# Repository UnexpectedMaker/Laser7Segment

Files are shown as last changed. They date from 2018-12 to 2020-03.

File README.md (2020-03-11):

# Laser7Segment Display Library
An API that lets you display numbers and letters on Laser7Segment RGB LED displays that are available from [tindie](https://www.tindie.com/products/seonr/laser-segment-display/)

You can find the Open Source hardware PCB design and Gerber files here too as well as the DXF laser cut design files

## Installing and Use
The downloaded code should be added to your arduino IDE libraries folder, and the library requires the [Adafruit NeoPixel library](https://github.com/adafruit/Adafruit_NeoPixel) for it to function.

To include the Laser7Segment library in your project:

    #include <Laser7Segment.h>

You can then initialise the display with the following line that includes the number of Laser7Segment digits and the GPIO to control them:

    Laser7Segment disp( 5, 4 );

You then start the display with the bebin method, passing the brightness:

    disp.Begin(80);

The you simply pass the display the String you would like displayed and a color:

    disp.DisplayText( "1234", disp.Color( 255,0,0) );

Enjoy!

# Support Unexpected Maker

I love designing, making and releasing our projects as open source. I do it because I believe it’s important to share knowledge and give back to the community, like many have done before me. It helps us all learn and grow.

That said, a lot of time, effort and finances have gone into designing and releasing these files, so please consider supporting me by buy some of my TiinyPICO products:

https://tinypico.com/shop

Or by buying one of our products on tindie:

https://www.tindie.com/stores/seonr/

Or by becoming a Patron:

https://www.patreon.com/unexpectedmaker

# Unexpected Maker
http://youtube.com/c/unexpectedmaker

http://twitter.com/unexpectedmaker

https://www.facebook.com/unexpectedmaker/

https://www.instagram.com/unexpectedmaker/

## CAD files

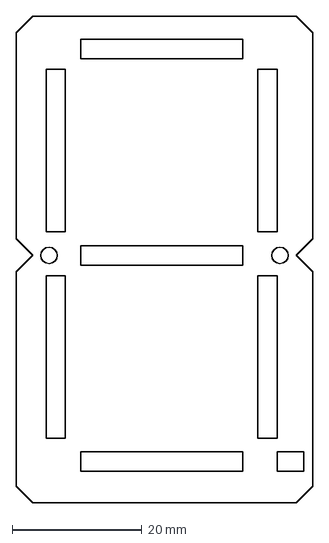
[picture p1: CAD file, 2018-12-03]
Design/LaserSegment_7_Segment_Back.dxf
45.7 x 74.9 mm

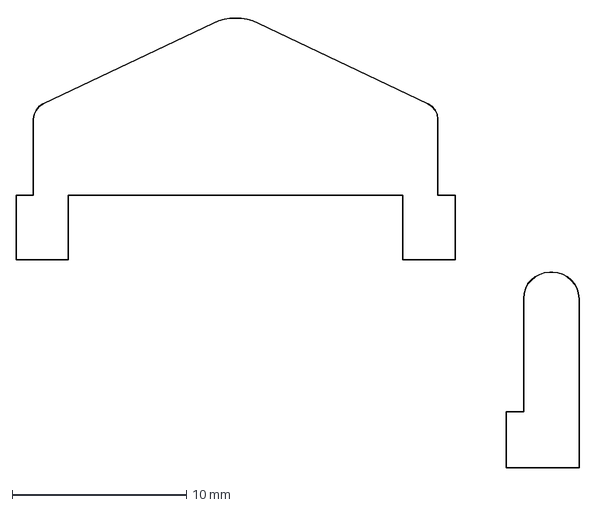
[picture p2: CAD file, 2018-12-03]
Design/LaserSegment_7_Segments.dxf
32.3 x 25.9 mm

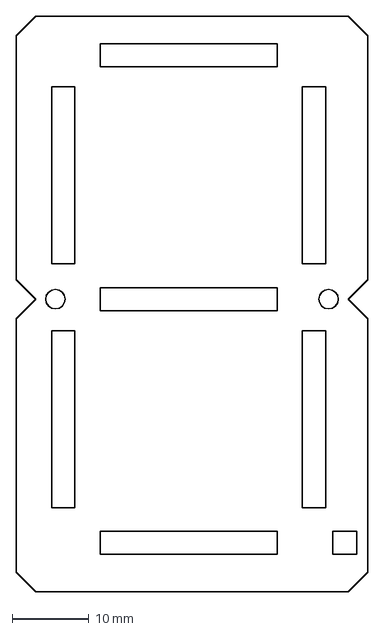
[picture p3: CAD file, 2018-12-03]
Design/LaserSegment_7_Segment_Front.dxf
45.7 x 74.9 mm

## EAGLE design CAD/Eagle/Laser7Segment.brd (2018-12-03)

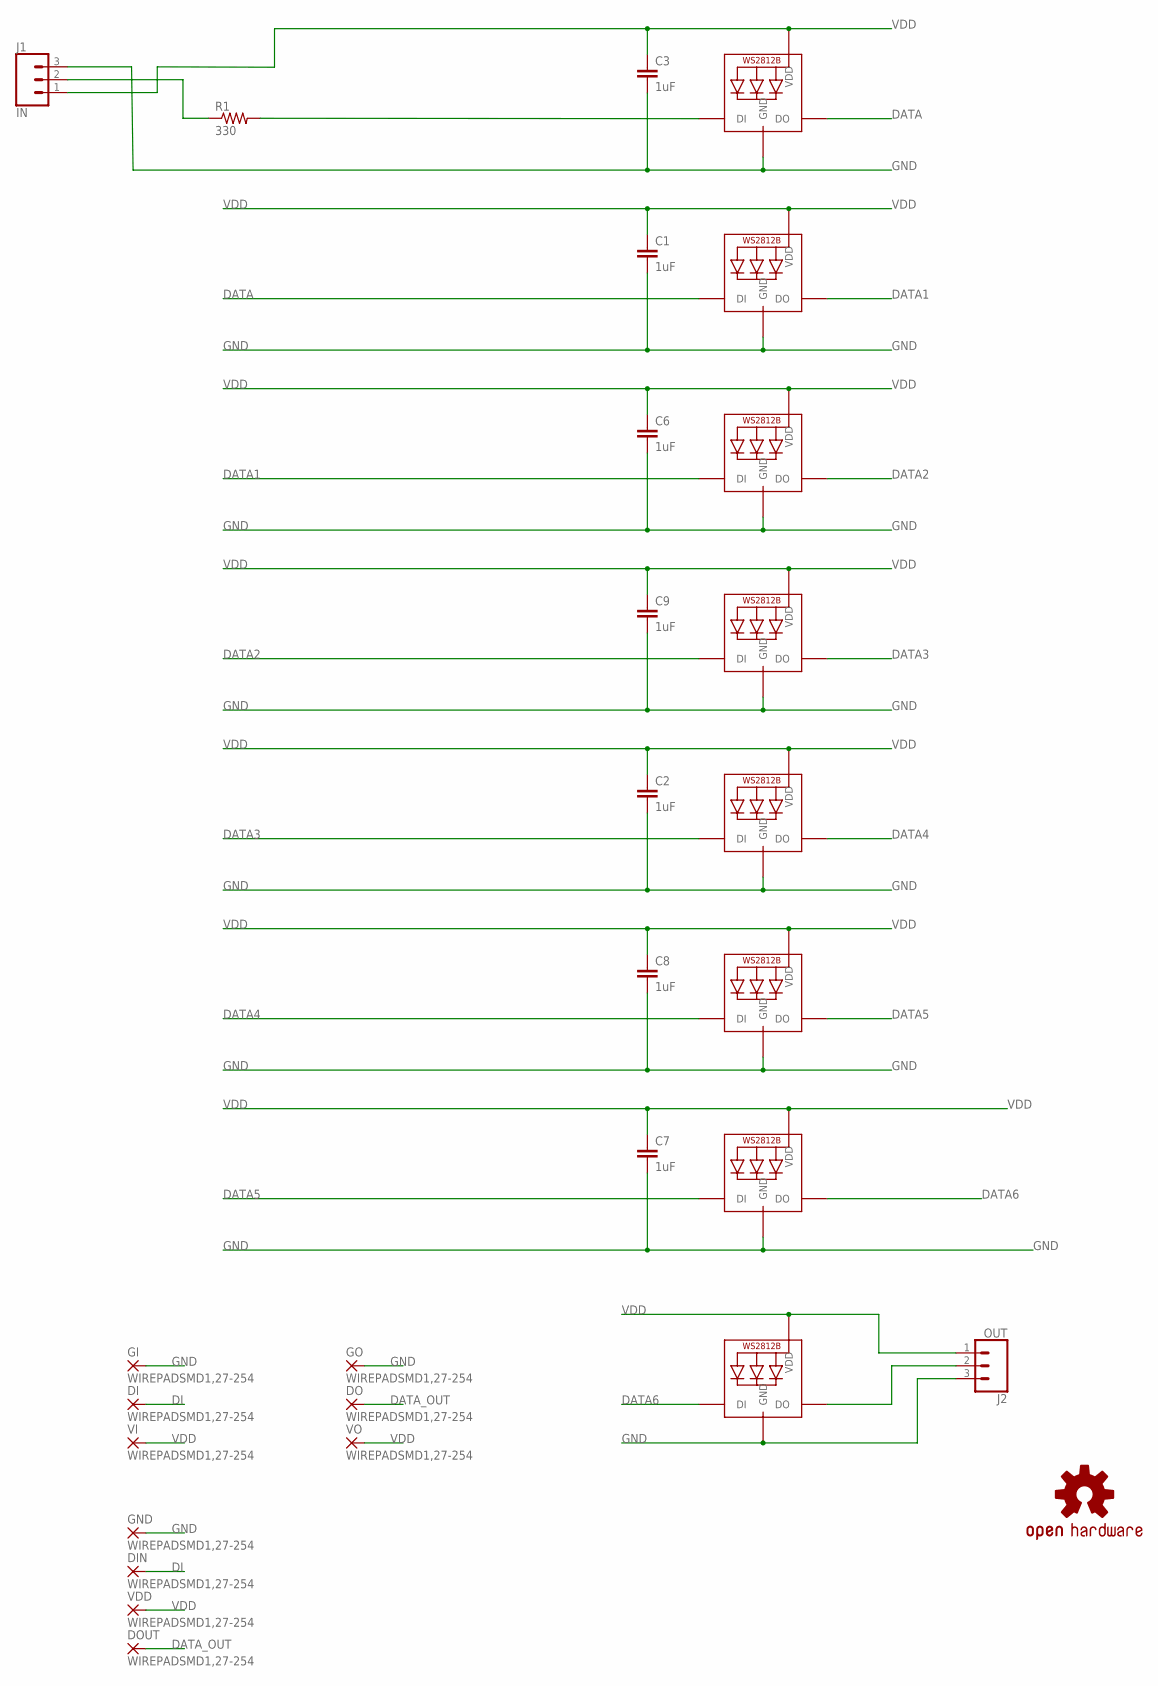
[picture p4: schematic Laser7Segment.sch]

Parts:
C1, C2, C3, C6, C7, C8, C9: 1uF; C0805
DI: WIREPADSMD1,27-254; SMD1,27-2,54
DIN: WIREPADSMD1,27-254; SMD1,27-2,54
DO: WIREPADSMD1,27-254; SMD1,27-2,54
DOUT: WIREPADSMD1,27-254; SMD1,27-2,54
GI: WIREPADSMD1,27-254; SMD1,27-2,54
GND: WIREPADSMD1,27-254; SMD1,27-2,54
GO: WIREPADSMD1,27-254; SMD1,27-2,54
J1: IN; 1X03_LONGPADS
J2: OUT; 1X03_LONGPADS
L1, L2, L3, L4, L5, L6, L7: WS2812B5050; WS2812B
L8: RGB 3535; LED3535
LOGO1: OSHW-LOGOM; OSHW-LOGO-M
R1: 330; R0805
VDD: WIREPADSMD1,27-254; SMD1,27-2,54
VI: WIREPADSMD1,27-254; SMD1,27-2,54
VO: WIREPADSMD1,27-254; SMD1,27-2,54

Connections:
DATA: L1.2-DOUT (DO), L2.4-DIN (DI)
DATA1: L2.2-DOUT (DO), L3.4-DIN (DI)
DATA2: L3.2-DOUT (DO), L4.4-DIN (DI)
DATA3: L4.2-DOUT (DO), L5.4-DIN (DI)
DATA4: L5.2-DOUT (DO), L6.4-DIN (DI)
DATA5: L6.2-DOUT (DO), L7.4-DIN (DI)
DATA6: L7.2-DOUT (DO), L8.1 (DI)
DATA_OUT: DO.1, DOUT.1, J2.2, L8.3 (DO)
DI: DI.1, DIN.1, J1.2, R1.1
DI_R: L1.4-DIN (DI), R1.2
GND: C1.2, C2.2, C3.2, C6.2, C7.2, C8.2, C9.2, GI.1, GND.1, GO.1, J1.3, J2.3, L1.3-GND (GND), L2.3-GND (GND), L3.3-GND (GND), L4.3-GND (GND), L5.3-GND (GND), L6.3-GND (GND), L7.3-GND (GND), L8.4 (GND)
VDD: C1.1, C2.1, C3.1, C6.1, C7.1, C8.1, C9.1, J1.1, J2.1, L1.1-VDD (VDD), L2.1-VDD (VDD), L3.1-VDD (VDD), L4.1-VDD (VDD), L5.1-VDD (VDD), L6.1-VDD (VDD), L7.1-VDD (VDD), L8.2 (VDD), VDD.1, VI.1, VO.1

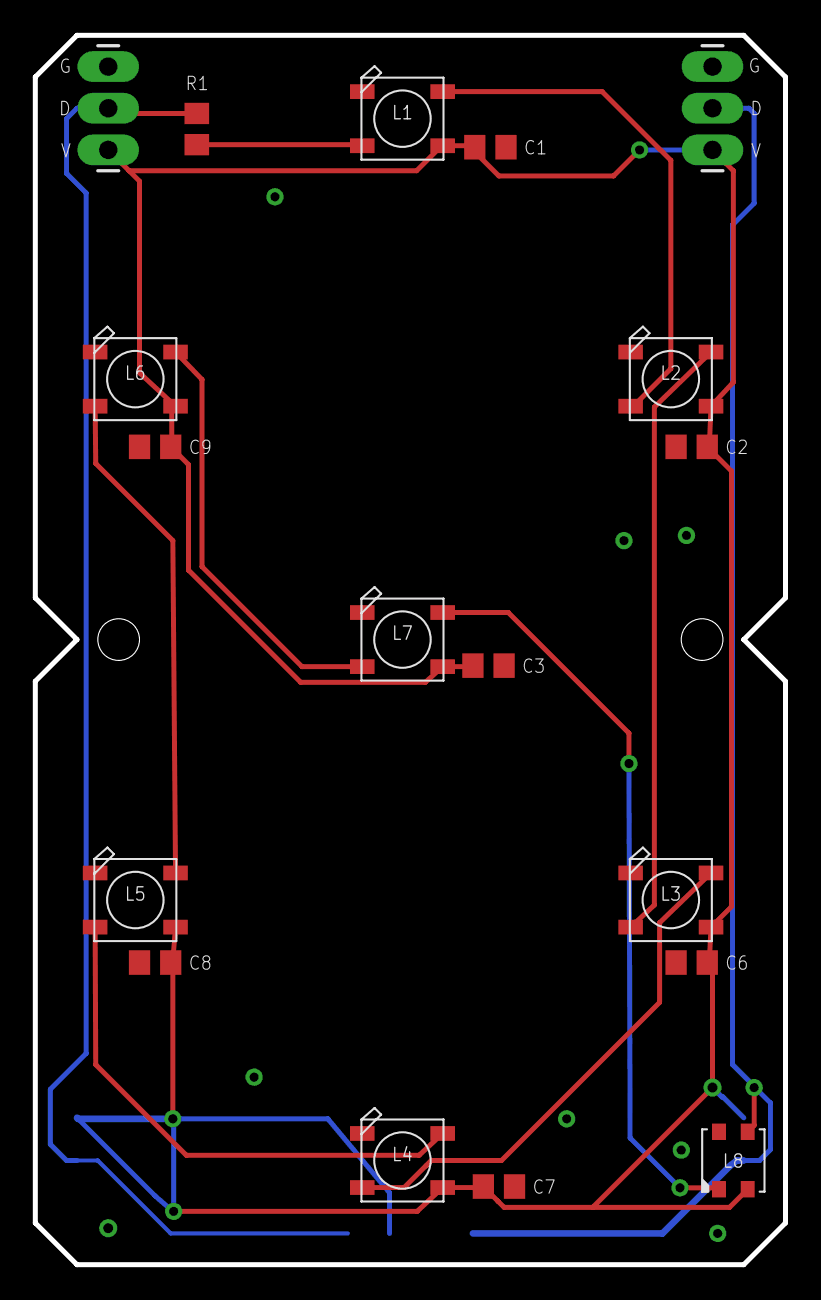
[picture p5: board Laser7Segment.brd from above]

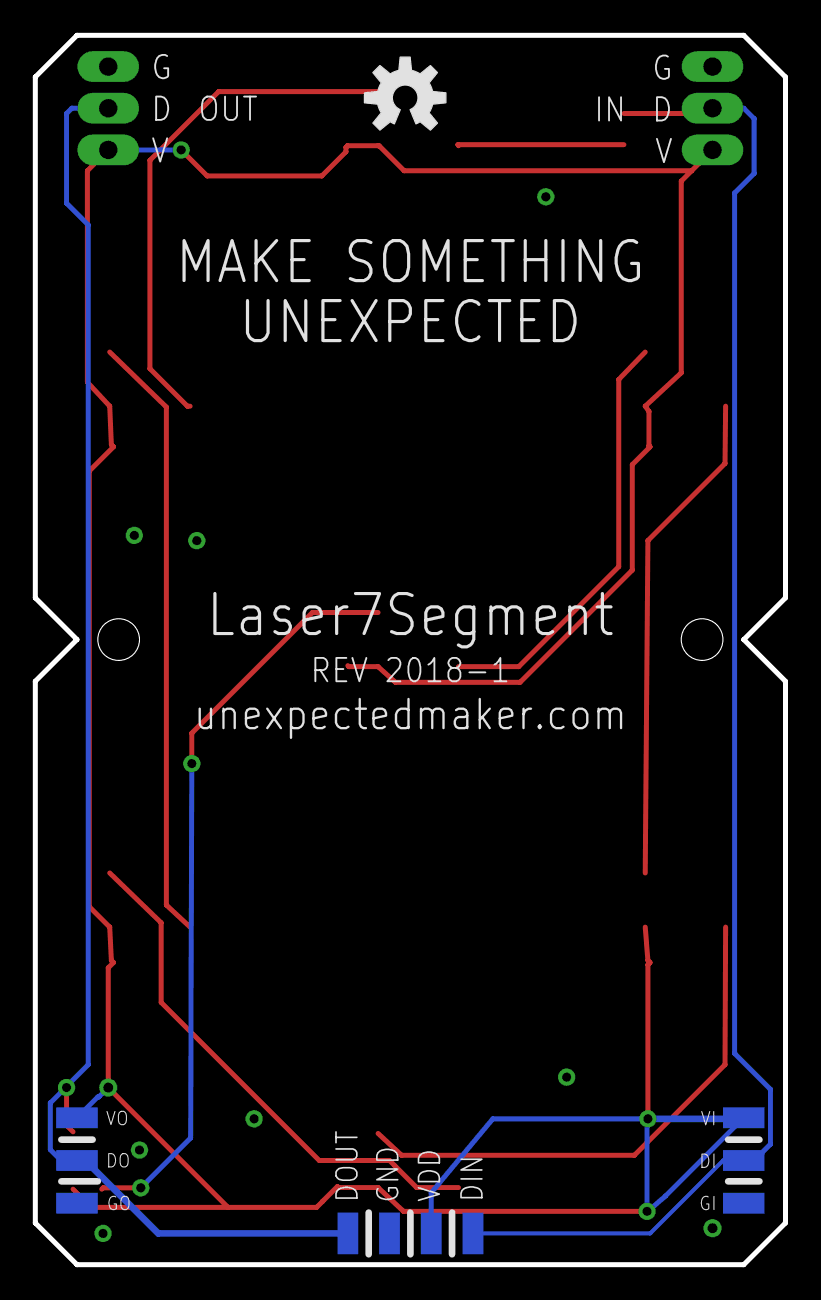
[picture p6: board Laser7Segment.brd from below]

Board: 2 copper layers, 45.7 x 74.9 mm, 29 parts (11 on the bottom side), 12 nets.

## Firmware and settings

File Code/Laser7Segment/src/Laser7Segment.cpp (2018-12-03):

// ---------------------------------------------------------------------------
// Created by Seon Rozenblum - seon@unexpectedmaker.com
// Copyright 2016 License: GNU GPL v3 http://www.gnu.org/licenses/gpl-3.0.html
//
// See "Laser7Segment.h" for purpose, syntax, version history, links, and more.
// ---------------------------------------------------------------------------

#include "Laser7Segment.h"
// This library is 100% entwined with the Adafruit NeoPixel library - please check their licensing terms in their library.
#include <Adafruit_NeoPixel.h>

// #define DEBUG 1
#define NUM_PIXELS_PER_BOARD 8

#define ELEMENTS(x)   (sizeof(x) / sizeof(x[0]))



// Array of pixels per segment, 7 segments with 4 pixels each
// int segmentsPixels[14][5] 	{ { 0, 1, 2, 3, 4 }, 
//                               { 5, 6, 7, 8, 9 }, 
//                               { 10, 11, 12, 13, 14 }, 
//                               { 15, 16, 17, 18, 19 }, 
//                               { 20, 21, 22, 23, 24 }, 
//                               { 25, 26, 27, 28, 29 }, 
//                               { 30, 31, 32, 33, 34 },
// 							  { 35, 36, 37, -1, -1 },
// 							  { 38, 39, 40, -1, -1 },
// 							  { 41, 42, 43, -1, -1 },
// 							  { 44, 45, 46, -1, -1 },
// 							  { 47, 48, 49, 50, 51 },
// 							  { 52, 53, 54, 55, 56 },
// 							  { 57, -1, -1, -1, -1}
// 						  	};

// Array of pixel positions in X,Y format for mapping colours in X,Y space
byte pixelsXY[8][2]		{ {1,0}, {0,1}, {2,1}, {1,2}, {0,3}, {2,3}, {1,4} ,{3,4} };

					  
// Array of segment based rainbow colour values
uint32_t segmentRainbow[7][3] {
                              { 255,0,0 },
                              { 255,124,42 },
                              { 255,255,0 },
                              { 69,223,91 },
                              { 31,189,255 },
                              { 150,11,255 },
                              { 255,30,237 }
                            };

// Available characters a 7 Segment display can show					  
const byte ARRAY_SIZE = 32;

CharacterX characters_pixel_upper[ ARRAY_SIZE ] {
	{ '0', 0b00111111 }, 
	{ '1', 0b00000110 },
	{ '2', 0b01011011 },
	{ '3', 0b01001111 },
	{ '4', 0b01100110 },
	{ '5', 0b01101101 },
	{ '6', 0b01111100 },
	{ '7', 0b00000111 },
	{ '8', 0b01111111 },
	{ '9', 0b01100111 },
	{ 'a', 0b01110111 },
	{ 'b', 0b01111111 },
	{ 'c', 0b00111001 },
	{ 'd', 0b00111111 },
	{ 'e', 0b01111001 },
	{ 'f', 0b01110001 },
	{ 'g', 0b01100111 },
	{ 'h', 0b01110110 },
	{ 'i', 0b00110000 },
	{ 'j', 0b00011110 },
	{ 'l', 0b00111000 },
	{ 'n', 0b00110111 },
	{ 'o', 0b00111111 },
	{ 'p', 0b01110011 },
	{ 'q', 0b01100111 },
	{ 'r', 0b00110001 },
	{ 's', 0b01101101 },
	{ 'u', 0b00111110 },
	{ 'x', 0b01110110 },
	{ 'y', 0b01101110 },
	{ '-', 0b01000000 },
	{ ' ', 0b00000000 }
};	
						
CharacterX characters_pixel[ ARRAY_SIZE ] {

	{ '0', 0b00111111 }, 
	{ '1', 0b00000110 },
	{ '2', 0b01011011 },
	{ '3', 0b01001111 },
	{ '4', 0b01100110 },
	{ '5', 0b01101101 },
	{ '6', 0b01111100 },
	{ '7', 0b00000111 },
	{ '8', 0b01111111 },
	{ '9', 0b01100111 },
	{ 'a', 0b01110111 },
	{ 'b', 0b01111111 },
	{ 'c', 0b00111001 },
	{ 'd', 0b00111111 },
	{ 'e', 0b01111001 },
	{ 'f', 0b01110001 },
	{ 'g', 0b01100111 },
	{ 'h', 0b01110110 },
	{ 'i', 0b00110000 },
	{ 'j', 0b00011110 },
	{ 'l', 0b00111000 },
	{ 'n', 0b00110111 },
	{ 'o', 0b00111111 },
	{ 'p', 0b01110011 },
	{ 'q', 0b01100111 },
	{ 'r', 0b00110001 },
	{ 's', 0b01101101 },
	{ 'u', 0b00111110 },
	{ 'x', 0b01110110 },
	{ 'y', 0b01101110 },
	{ '-', 0b01000000 },
	{ ' ', 0b00000000 }
};

													
Laser7Segment::Laser7Segment( uint8_t displayCount, uint8_t dPin )
{
	dispCount = displayCount;
	dispPin = dPin;
	pixels = Adafruit_NeoPixel ();
	pixels.updateType( NEO_GRB + NEO_KHZ800 );
  	pixels.updateLength( dispCount * NUM_PIXELS_PER_BOARD );
  	pixels.setPin(dispPin);
	isReady = false;
}

Laser7Segment::~Laser7Segment()
{
	isReady = false;
}

bool Laser7Segment::IsReady()
{
	return isReady;
}

void Laser7Segment::Begin( uint8_t brightness )
{

	pixels.begin(); // This initializes the NeoPixel library.
	pixels.show();
	pixels.setBrightness( brightness );

	cachedString = "";
	cachedCharacters = ( CharacterX *) malloc(dispCount * sizeof(CharacterX) );
	cachedBytes = ( uint8_t *) malloc(dispCount * sizeof(uint8_t) );
	
	// Set all cached bytes to 0
	for ( int i = 0; i < dispCount; i++ )
		cachedBytes[i] = 0;

	#ifdef DEBUG
		Serial.print("Brightness: ");
		Serial.println(brightness);
		Serial.println("Ready!");
	#endif

	//Digits are initialised and ready
	isReady = true;
	isForcedUpper = false;
}

void Laser7Segment::Clear( uint8_t display )
{
	if ( isReady )
	{
		for ( int p = 0; p < NUM_PIXELS_PER_BOARD; p++ )
			pixels.setPixelColor( p + ( display * NUM_PIXELS_PER_BOARD ), Color(0,0,0) );

		pixels.show();
	}
}

void Laser7Segment::SetBrightness( uint8_t brightness )
{
	if ( isReady )
	{
		pixels.setBrightness( brightness );
	}
}


byte Laser7Segment::GetArraySize()
{
	return ARRAY_SIZE;
}

void Laser7Segment::ForceUppercase( bool force )
{
	isForcedUpper = force;
}

// Character Laser7Segment::GetCharacterByByte( uint16_t id )
// {
// 	for ( int i = 0; i < ELEMENTS( available_characters ); i++ )
// 	{
// 		if ( available_characters[i].segments == id )
// 			return available_characters[i];
// 	}

// 	return available_characters[0];
// }

// Character Laser7Segment::FindCharacter( byte c )
// {
// 	for ( int i = 0; i < ELEMENTS( available_characters ); i++ )
// 	{
// 		if ( available_characters[i].id == c )
// 			return available_characters[i];
// 	}

// 	return available_characters[0];
// }

CharacterX Laser7Segment::FindCharacterX( char c )
{

	for ( int i = 0; i < ELEMENTS( characters_pixel ); i++ )
	{
		Serial.println( String(i) +" " + String(characters_pixel[i].id) +" " + String(c) );
		if ( characters_pixel[i].id == c )
		{
			if ( isForcedUpper )
				return characters_pixel_upper[i];
			else
				return characters_pixel[i];
		}
	}

	return characters_pixel[0];
}



String Laser7Segment::GetCharacterAtArrayIndex( int index )
{
	return ( (String)(char)characters_pixel[ index ].id );
}

// Convert separate R,G,B into packed 32-bit RGB color.
// Packed format is always RGB, regardless of LED strand color order.
uint32_t Laser7Segment::Color(uint8_t r, uint8_t g, uint8_t b)
{
  return ((uint32_t)r << 16) | ((uint32_t)g <<  8) | b;
}
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

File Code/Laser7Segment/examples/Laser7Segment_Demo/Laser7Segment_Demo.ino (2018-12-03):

#include <Laser7Segment.h>

// Initalise the display with 1 Laser7Segment board connected to GPIO 12
Laser7Segment disp( 1, 12 );

int loopIndex = 0;
byte rainbowIndex = 0;
unsigned long nextRainbow = 0;
int displayFeature = 0;
int nextSwitch = 10000;

void setup()
{
  Serial.begin(115200);
  delay(1000);

  // Start the display with a brightness value of 80
  disp.Begin(80);

  // Set the initial display feature to show as 0
  displayFeature = 0;
}

void loop()
{

  // Wait until the display is initialised before we try to show anything
  if ( !disp.IsReady() )
  {
    nextSwitch = millis();
    return;
  }

  // Switch what we are showing every 5 seconds
  if ( millis() > nextSwitch )
  {
    nextSwitch = millis() + 5000;
   displayFeature = ( displayFeature + 1 ) % 7;
    Serial.println( "Showing feature: "+ String(displayFeature) );
  }

  // Display stuff on the Laser7Segment displays
  if ( nextRainbow < millis() )
  {
    switch( displayFeature )
    {
      
      case 0:
        disp.DisplayTextColorCycle( "12345", rainbowIndex );
        nextRainbow = millis() + 10;
        rainbowIndex++;
        break;

      case 1:
        disp.DisplayTextVerticalRainbow("     ", disp.Color(255,0,0), disp.Color(0,0,255) );
        delay(250);
        disp.DisplayTextVerticalRainbow("C    ", disp.Color(255,0,0), disp.Color(0,0,255) );
        delay(250);
        disp.DisplayTextVerticalRainbow("CL   ", disp.Color(255,0,0), disp.Color(0,0,255) );
        delay(250);
        disp.DisplayTextVerticalRainbow("CLE  ", disp.Color(255,0,0), disp.Color(0,0,255) );
        delay(250);
        disp.DisplayTextVerticalRainbow("CLEA ", disp.Color(255,0,0), disp.Color(0,0,255) );
        delay(250);
        disp.DisplayTextVerticalRainbow("CLEAR", disp.Color(255,0,0), disp.Color(0,0,255) );
        delay(1250);
        disp.DisplayTextVerticalRainbow(" LEAR", disp.Color(255,0,0), disp.Color(0,0,255) );
        delay(250);
        disp.DisplayTextVerticalRainbow("  EAR", disp.Color(255,0,0), disp.Color(0,0,255) );
        delay(250);
        disp.DisplayTextVerticalRainbow("   AR", disp.Color(255,0,0), disp.Color(0,0,255) );
        delay(250);
        disp.DisplayTextVerticalRainbow("    R", disp.Color(255,0,0), disp.Color(0,0,255) );
        delay(250);
        disp.DisplayTextVerticalRainbow("     ", disp.Color(255,0,0), disp.Color(0,0,255) );
        delay(500);
        nextSwitch = 0;
        break;

      case 2:
        disp.ForceUppercase( false );
        disp.DisplayTextVerticalRainbow("8BCDE", disp.Wheel( rainbowIndex & 255 ) , disp.Wheel( ( rainbowIndex + 50 ) & 255 )  );
        nextRainbow = millis() + 10;
        rainbowIndex--;
        break;
        

       case 3:
        disp.ForceUppercase( false );
        disp.DisplayTextHorizontalRainbow("67890", disp.Wheel( rainbowIndex & 255 ) , disp.Wheel( ( rainbowIndex + 150 ) & 255 )  );
        nextRainbow = millis() + 10;
        rainbowIndex--;
        break;

      
      case 4:
        disp.DisplayTime( 22, 16, (nextRainbow % 60), disp.Color(255, 200, 0), disp.Color(0, 0, 255) );
        nextRainbow = millis() + 500;
        break;

      case 5:
        disp.DisplayTextColorCycle( "0....0", rainbowIndex );
        nextRainbow = millis() + 10;
        rainbowIndex++;
        break;

       case 6:
         for ( int i = 0; i < disp.GetArraySize(); i++ )
         {
            disp.DisplayTextColor( disp.GetCharacterAtArrayIndex(i), disp.Wheel( rainbowIndex & 255 ) );
            rainbowIndex+=10;
            delay(250);
          }
          break;

    }
  }
}

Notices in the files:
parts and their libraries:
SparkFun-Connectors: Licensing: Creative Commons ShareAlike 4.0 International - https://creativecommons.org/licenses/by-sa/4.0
